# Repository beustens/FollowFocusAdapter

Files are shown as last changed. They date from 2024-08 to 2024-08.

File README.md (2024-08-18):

# Follow Focus Adapter
Fully parameterizable, 3D-printable gears for camera lens rings



## Description
This project provides OpenSCAD code to generate 3D files of gears which can be 3D-printed and clampled on camera (focus) rings with given diameter. These follow focus adapters support
- [Screw](#screw-fastener) or [cabletie](#cable-tie-fastener) fastener
- 360° rotation
- Focus tab

The gears have a module of 0.8 by default, which can be changed in the `adapter_*.scad` files.

## How to
1. Download [OpenSCAD](https://openscad.org/downloads.html) and this repository
1. Open [custom_params.scad](custom_params.scad) with OpenSCAD and enter the [parameters](#adapter-parameters) for your focus ring
1. Depending on your preferred [fastening method](#fastener-options), open
    - [adapter_cabletie.scad](adapter_cabletie.scad) or 
    - [adapter_screw.scad](adapter_screw.scad) and [screw_head.scad](screw_head.scad)
1. Go to `Design -> render` and then `File -> export -> STL` to generate the 3D-file

### Adapter parameters
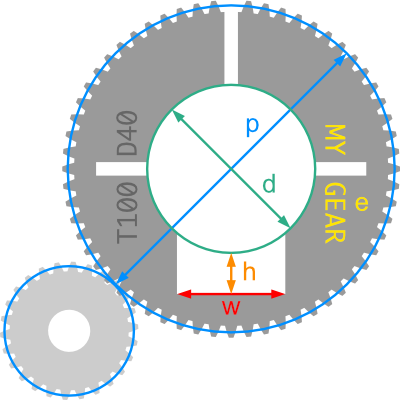
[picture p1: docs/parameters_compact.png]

- d = `focusringDiameter`: Diameter of your focus ring in mm
- w = `tabWidth`: When the focus ring has an focus tab, this is the width in mm. Otherwise set to 0
- h = `tabHeight`: When the focus ring has an focus tab, this is the height in mm. Otherwise set to 0
- p = `wantedPitchDiameter`: Optional minimum pitch diameter when a larger gear is preferred. Note that due to even number of teeth, the actual pitch diameter may be sightly larger. It will be shown in OpenSCAD when generating the adapter
- e = `engravingTextL1` and `engravingTextL1`: Optional custom engraving text. Note that the number of teeth (T) and the ring diameter (D) will always be engraved automatically too. That way, you can calculate the pitch diameter by 0.8 x T and the outer diameter by 0.8 x (T + 2)

## Fastener options
The adapter can be generated with a screw or cabletie fastener

### Screw fastener
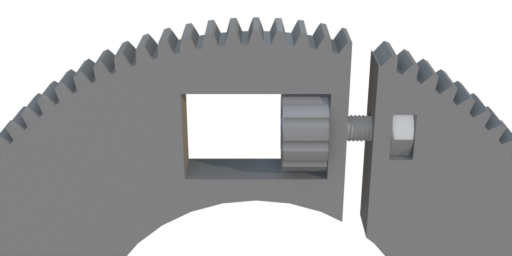
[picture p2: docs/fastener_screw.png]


Fastening with a screw has the advantage that the adapter can be easily fixated and loosened without additional tools.

Generate the 3D-files from [adapter_screw.scad](adapter_screw.scad) and [screw_head.scad](screw_head.scad).

Additionally, you will need
- an M3 x 10mm or 12mm hex cap screw (DIN 933 / ISO 4017) and 
- an M3 hex nut (DIN 934 / ISO 4030) or even better quad nut (DIN 562).

### Cable tie fastener
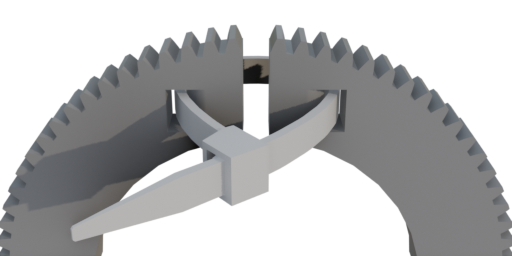
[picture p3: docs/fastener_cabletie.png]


Fastening with a cable tie has the advantage that the adapters' outer diameter is smaller.

Generate the 3D-file from [adapter_cabletie.scad](adapter_cabletie.scad).

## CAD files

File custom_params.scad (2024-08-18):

focusringDiameter = 40; // focus ring diameter in mm
tabWidth = 20; // focus tab largest width in mm
tabHeight = 10; // focus tab height (distance focusring <-> peak of tab) in mm
wantedPitchDiameter = 0; // minimum pitch diameter
engravingTextL1 = ""; // first line custom text
engravingTextL2 = ""; // second line custom text

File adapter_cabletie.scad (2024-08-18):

include <involute_gear.scad>; // to build gears and get some gear functions
include <custom_params.scad>; // customer parameters

// parameters by design
focusringDepth = 5.5; // depth of the focus ring in mm
engrave = true;

// parameters by constraints
ffMod = 0.8; // module
looseFit = 0.3; // padding to make 3D printed parts fit loosely on real objects
bestFit = 0.2; // padding to make 3D printed parts fit perfectly on real objects
antiFit = 1; // wall-on-wall does not work in openSCAD

// calculate grip cutout parameters
focusringRadius = focusringDiameter/2;
gripPeak = sqrt(pow(tabWidth/2, 2)+pow(focusringRadius+tabHeight, 2));
gripCutoutWidth = tabWidth+min(2*bestFit, tabWidth); // min to prevent cutout by fit when width/height 0
gripCutoutHeight = tabHeight+focusringRadius+min(2*bestFit, tabHeight);

// separator slit parameters
slitWidth = 3;

// cable tie slit parameters
cabletiePad = 1; // distance to focusring at separator slit center
cabletieDist = 10; // cable tie distance to separator slit
cabletieWidth = 1.5+2*looseFit;
cabletieHeight = 4.5+2*looseFit;
cabletieBoxWidth = focusringDepth/2+cabletieWidth;
cabletiePeak = sqrt(pow(cabletieDist, 2)+pow(focusringRadius+cabletieHeight+cabletiePad, 2));

// gear parameters
gearStability = 3; // gap between pitch radius grip to give some stability
minPeak = max(gripPeak, cabletiePeak, wantedPitchDiameter/2-gearStability); // minimum peak, either let cabletie or grip dominate
minPitchRadius = minPeak+gearStability; // minimum pitch radius
// calculate number of teeth for a wanted pitch radius
widthTooth = modToPitch(ffMod); // get circular pitch
numTeeth = ceil(2*pi*minPitchRadius/widthTooth); // round up tooths
// print informations
outerDiameter = 2*outerRadius(widthTooth, numTeeth);
pitchDiameter = 2*pitchRadius(widthTooth, numTeeth);
echo("Gear properties:");
echo("teeth = ", numTeeth);
echo("pitch-diameter = ", pitchDiameter);
echo("outer-diameter = ", outerDiameter);
// depth to cutout from gear
gearCutoutDepth = focusringDepth+antiFit;

// further slit parameters
slitHeight = outerDiameter/2;

// spring cutout parameters
springThickness = 3;
springWidth = 2*sqrt(pow(minPeak, 2)-pow(springThickness/2, 2));

// engraving parameters
engravingTextR1 = str("T", numTeeth);
engravingTextR2 = str("D", focusringDiameter);
engravingFont = "Liberation Mono";
engravingSize = 4.5;
engravingDepth = 0.5;
engravingPlace = focusringRadius+cabletiePad; // distance from center
engravingPad = slitWidth/2+1; // to move text from slit away

// build adapter
difference() {
    // gear
    gear(
        pitch=widthTooth, 
        teeth=numTeeth, 
        thickness=focusringDepth, 
        holeDiameter=focusringDiameter+bestFit*2);
    
    // grip cutout
    translate([0, gripCutoutHeight/2, 0]) cube([gripCutoutWidth, gripCutoutHeight, gearCutoutDepth], center=true);

    // cable tie slits
    for (i = [0:1]) {
		rotate(a=i*180, v=[0, 1, 0]) {
            translate([-(cabletieDist-cabletieBoxWidth/2), -(focusringRadius+cabletieHeight/2+cabletiePad), 0]) {
                difference() {
                    // slit
                    cube([cabletieBoxWidth, cabletieHeight, focusringDepth+antiFit], center=true);
                    // rounding
                    translate([cabletieBoxWidth/2, 0, 0]) rotate(a=90, v=[1, 0, 0]) cylinder(h=cabletieHeight, d=focusringDepth+0.1, center=true, $fn=24);
                }
            }
        }
    }
    
    // separator slit
    translate([0, -slitHeight/2, 0]) cube([slitWidth, slitHeight+antiFit, gearCutoutDepth], center=true);
    
    // spring
    cube([springWidth, springThickness, gearCutoutDepth], center=true);

    if (engrave) {
        // generated text
        rotate(a=-90, v=[0, 0, 1]) translate([0, -engravingPlace, focusringDepth/2-engravingDepth]) rotate(a=180, v=[0, 0, 1]) linear_extrude(height=engravingDepth+antiFit) {
            // left bottom
            translate([-(slitWidth/2+1), 0, 0]) text(text=engravingTextR1, font=engravingFont, size=engravingSize, halign="right", valign="bottom");
            // right bottom
            translate([slitWidth/2+1, 0, 0]) text(text=engravingTextR2, font=engravingFont, size=engravingSize, halign="left", valign="bottom");
        }
    
        // custom text
        rotate(a=90, v=[0, 0, 1]) translate([0, -engravingPlace, focusringDepth/2-engravingDepth]) rotate(a=180, v=[0, 0, 1]) linear_extrude(height=engravingDepth+antiFit) {
            // left bottom
            translate([-(slitWidth/2+1), 0, 0]) text(text=engravingTextL1, font=engravingFont, size=engravingSize, halign="right", valign="bottom");
            // right bottom
            translate([slitWidth/2+1, 0, 0]) text(text=engravingTextL2, font=engravingFont, size=engravingSize, halign="left", valign="bottom");
        }
    }
}

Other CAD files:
adapter_screw.scad
involute_gear.scad
screw_head.scad
small_gear_example.scad
